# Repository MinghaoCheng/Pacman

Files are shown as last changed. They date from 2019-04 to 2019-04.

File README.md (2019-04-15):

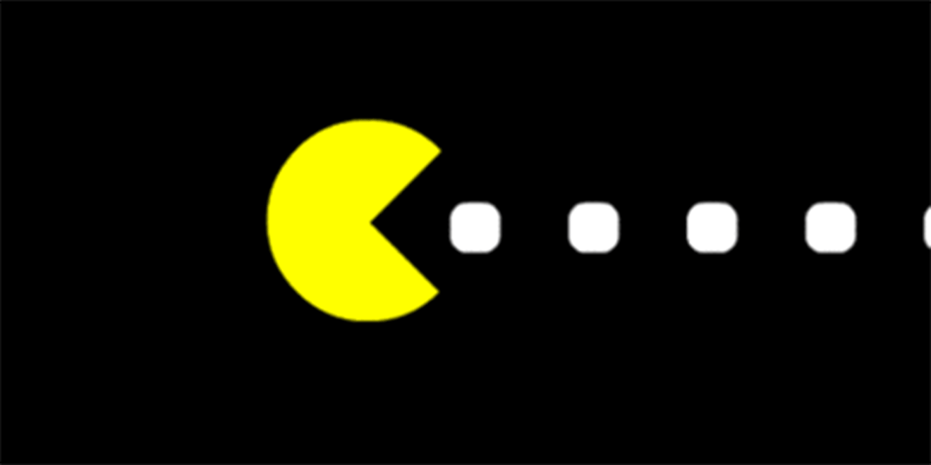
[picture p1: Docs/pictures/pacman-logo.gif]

# Pacman
ENG5220, Embedded real-time programming project, Team19

|Author|Team 19|
|---|---
|E-mail|2359434c@student.gla.ac.uk

* The follwing link is two demostrations of playing the game, catched by the ghost and won the game
https://www.youtube.com/playlist?list=PLmhQhGby8E4eoPKThM3S1RnaBH7sxEcJI

## Motivation& Introduction

As a classic computer game, Pacman impressed lots of people. Now we can do a Pacman game in real life!

This project uses a game panel which contains two 4x4 LED matrices. One of them is in green working as Pacdots, and the other one is in red to represent the Ghost. There is also a 4x4 LDR matrix to give feedback to the host. Three matrices are on the same place and controlled by the host raspberryPi.

There is a car controlled by a raspberryPi which acts as Pacman. It can move around upon the pannel, eat Pacdots and hide from the Ghost.

## Table of contents
* [Getting started](#getting_started)
* [System overview](#system_overview)
* [Required components(BOM)](#required_components(BOM))
* [Assemble](#assemble)
* [Software](#software)
* [Found a bug](#found_a_bug)
* [License](#license)
## Getting started 
1. Buiding hardware  
      Hardware contains PCBs, mechanics, sodering, see [Hardware](#hardware) for details.  
2. Built& install software  
    1. Host  
      To build the software of host: on host raspberryPi, type ```./build_host.sh``` in terminal.  
      To install the software of host:type ```sudo ./install_host.sh``` in terminal. (Only the kernel module needs to be installed)  
    2. Car  
      To build the software of car: on car raspberryPi, type ```./build_car.sh``` in terminal.
3. Execute the programme  
    1. Host  
      Type "sudo ./host_exe" in terminal. (Because this programme would access the kernel module, so it requires super_user)  
    2. Car  
      Type "./car_exe" in terminal.
4. Game rules  
      Once the game starts(After the background music), the Pacdots(green LEDs) would all be on. The Pacman(the Car) would follow the instructions of keyboard connected to the host. If the Pacman eats a Pacdot (car hits the green LED), the LDR would give feedback to the host and shut down the corresponding LED. Meanwhile, a sound would give the player a feedback. The player would win the game when all Pacdots are eaten (a winning music would be played). There is only one ghost(red LED), which would move randomly, if the Pacman hits the ghost, the player will lose (a losing music would be played).  
5. Have fun!  

## System overview
* This project contains a host and a car. The host does the following work:  
    ** Control a red LED matrix using a GPIO extender "MCP23S17" to display the location of the ghost
    ** Control a green LED matrix using a GPIO extender "MCP23S17" to display the pacdots
    ** Control a LDR matrix as the feedback of location of the car
    ** Handle a TCP/IP connection as the server, and send instructions to the car via the connection
    ** Connect with a simple keyboard as input
    ** Output sound through 3.5mm audio jack (Using function "system()" now, I would add ALSA sound driver later)  
* The car work as follow:
    ** Handle a TCP/IP connection as client to receive instructions from the host
    ** Control two motors(which drive the wheels of the car) through a dual H-bridge IC "L298N"
    ** The car sink current from 4xAA batteries and a 5V3A LDO is used.

## Required components(BOM)
* host_0 board

|Component|Quantity|Farnell code|
|---|---|---
|4816P-T02-222LF|1|2908136
|LM2901D|4|1648673
|Resistor,2kΩ,R0805|1|1469887
|Resistor,10kΩ,R0805|2|1469856
|MCP23S17T-E/SS|1|2775058
|pin header 2x8, bended, 2.54mm|2|2984492
|Capacitor, 0.1uF, C0603|1|2280842
|M20-6102045,Connector|1|1569230

* host_1 board

|Component|Quantity|Farnell code|
|---|---|---
|MCP23S17T-E/SS|1|2775058
|BCW66GLT1G|4|2317524
|BCW68GLT1G|4|2317538
|4816P-1-102LF|2|1612549
|M20-6102045,Connector|1|1569230
|pin header 2x8, bended, 2.54mm|1|2984492
|Capacitor, 0.1uF, C0603|1|2280842
|Resistor,200Ω,R0805*|8|1894175

    *:optional,depends on the impedence of the LEDs  

* car_0 board

|Component|Quantity|Farnell code|
|---|---|---
|L298N|1|403295
|NCP59301DS50R4G|1|2774711
|BYG10M-E3/TR|8|9549170
|Capacitor, 0.1uF, C0805|2|

* Others

|Component|Quantity|Farnell code|
|---|---|---
|RapsberryPi model 3B|2|
|Green LED*|16|
|Red LED*|16|
|LDR|16|3168335
|Wires|N/A|
|Panel**|1|

    *:could use any LEDs under 100mA, but the resistors on host_1 board needs to be adjusted  
    **:In this project, the panel was made of a cardboard.
## Assemble
* For PCBs of the host, connect them in the way as follow:  

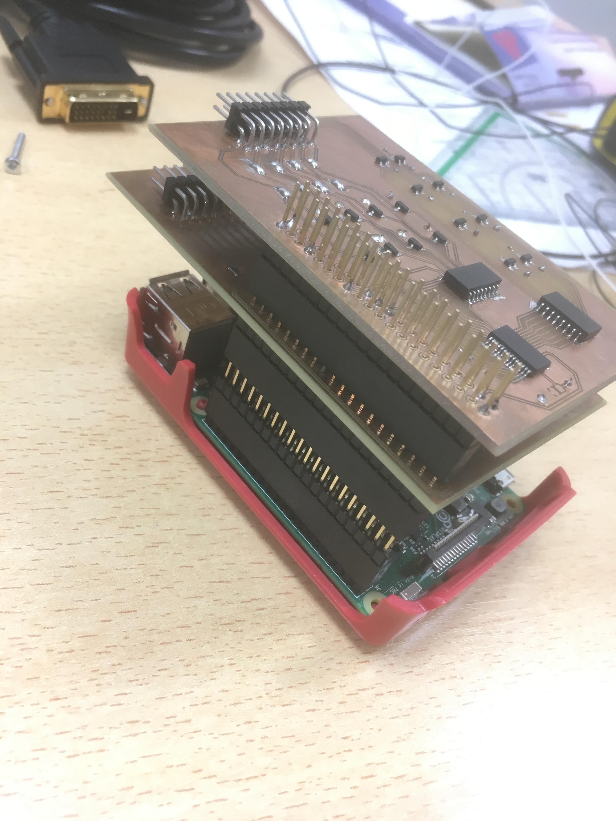
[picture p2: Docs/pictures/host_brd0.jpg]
  

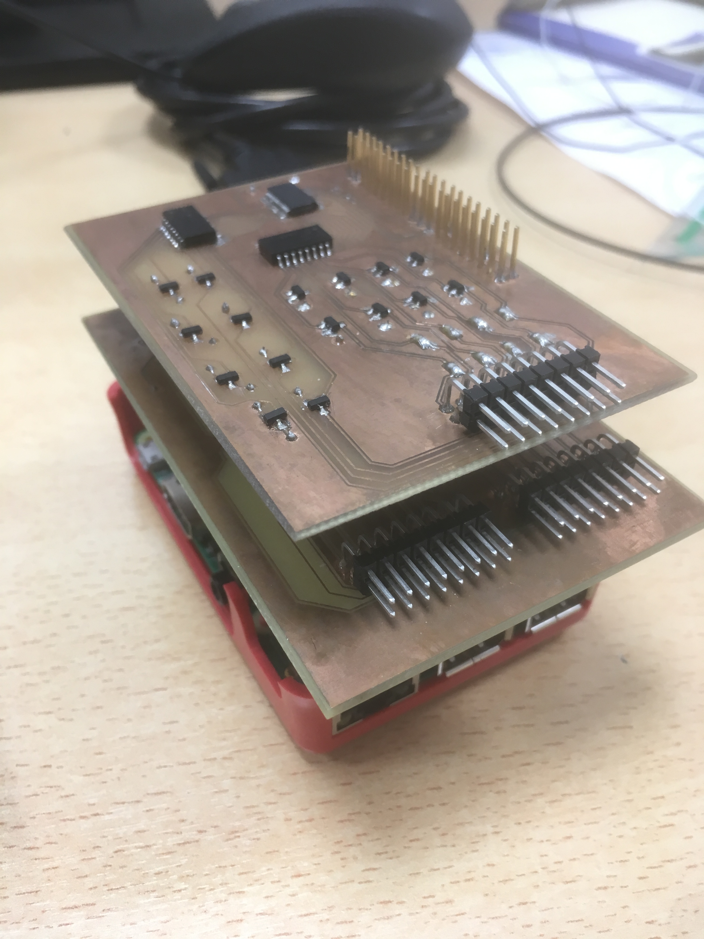
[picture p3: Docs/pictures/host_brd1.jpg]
  

* For LED&LDR matrices, put one green LED, one red LED and one LDR at a single hole on the panel(There are 4x4 holes). Note to put LDR above the LEDs.  

  

* Solder green LED matrix/red LED matrix as follow, this schematic also can be found at [PCBs](/Docs/PCBs):

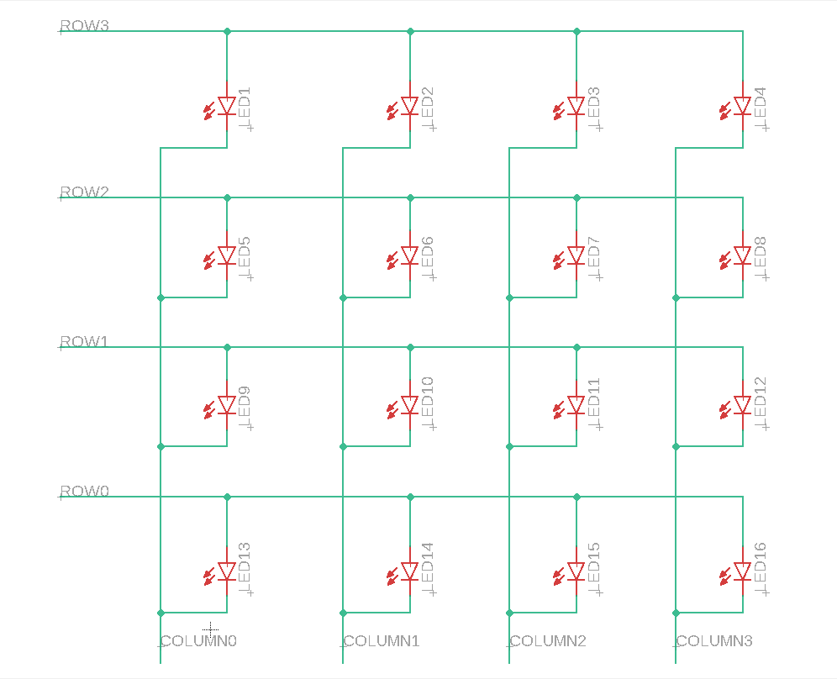
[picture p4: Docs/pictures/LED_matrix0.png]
 

* Solder keyboard following the schematic

* Picture of the system set





## Software
* There are two source codes in this project. One works on the host and another one works on the car.  
* The software of the host contains a kernel module which would work as the driver of the GPIO(it handles GPIO interrupt and output of the GPIO used by the host), and it contains the main codes which works in the user space. There are several components of this software, see details at [Docs](/Docs/software/host)  
* The software of the car controls the motor using L298N through GPIO, and it also receives instructions from the host over TCP/IP through Wi-Fi connection. See details at [Docs](/Docs/software/car)   
* dependency:  
      * host:
      ```pthread, rt, ```
      * car:
      ```pthread```
## Found a bug<a name="found_a_bug">
* Hardware:  
      To isolate the fault of the hardware, the best way is to check the PCB-layouts and schematics.  
      Here is the definition of pins used by the host:  
      
|Raspi-pin|Function|
|---|---
|03|Reset of MCP23S17(s)
|05|INT B of MCP23S17 of LDR board
|07|INT A of MCP23S17 of LDR board
|19|MOSI of SPI bus
|21|MISO of SPI bus
|23|CLK of SPI bus
|24|CS_0 of SPI bus, LDR board
|26|CS_1 of SPI bus, LED board
|29|Keyboard, Left
|31|Keyboard, Up
|33|Keyboard, Right
|35|Keyboard, Down
|37|Keyboard, Reset
      
* Software:
      Remember to add "sudo" to install the host kernel module and execute the programme
      
* For other questions, you can send me an Email with description

## License
See license.md

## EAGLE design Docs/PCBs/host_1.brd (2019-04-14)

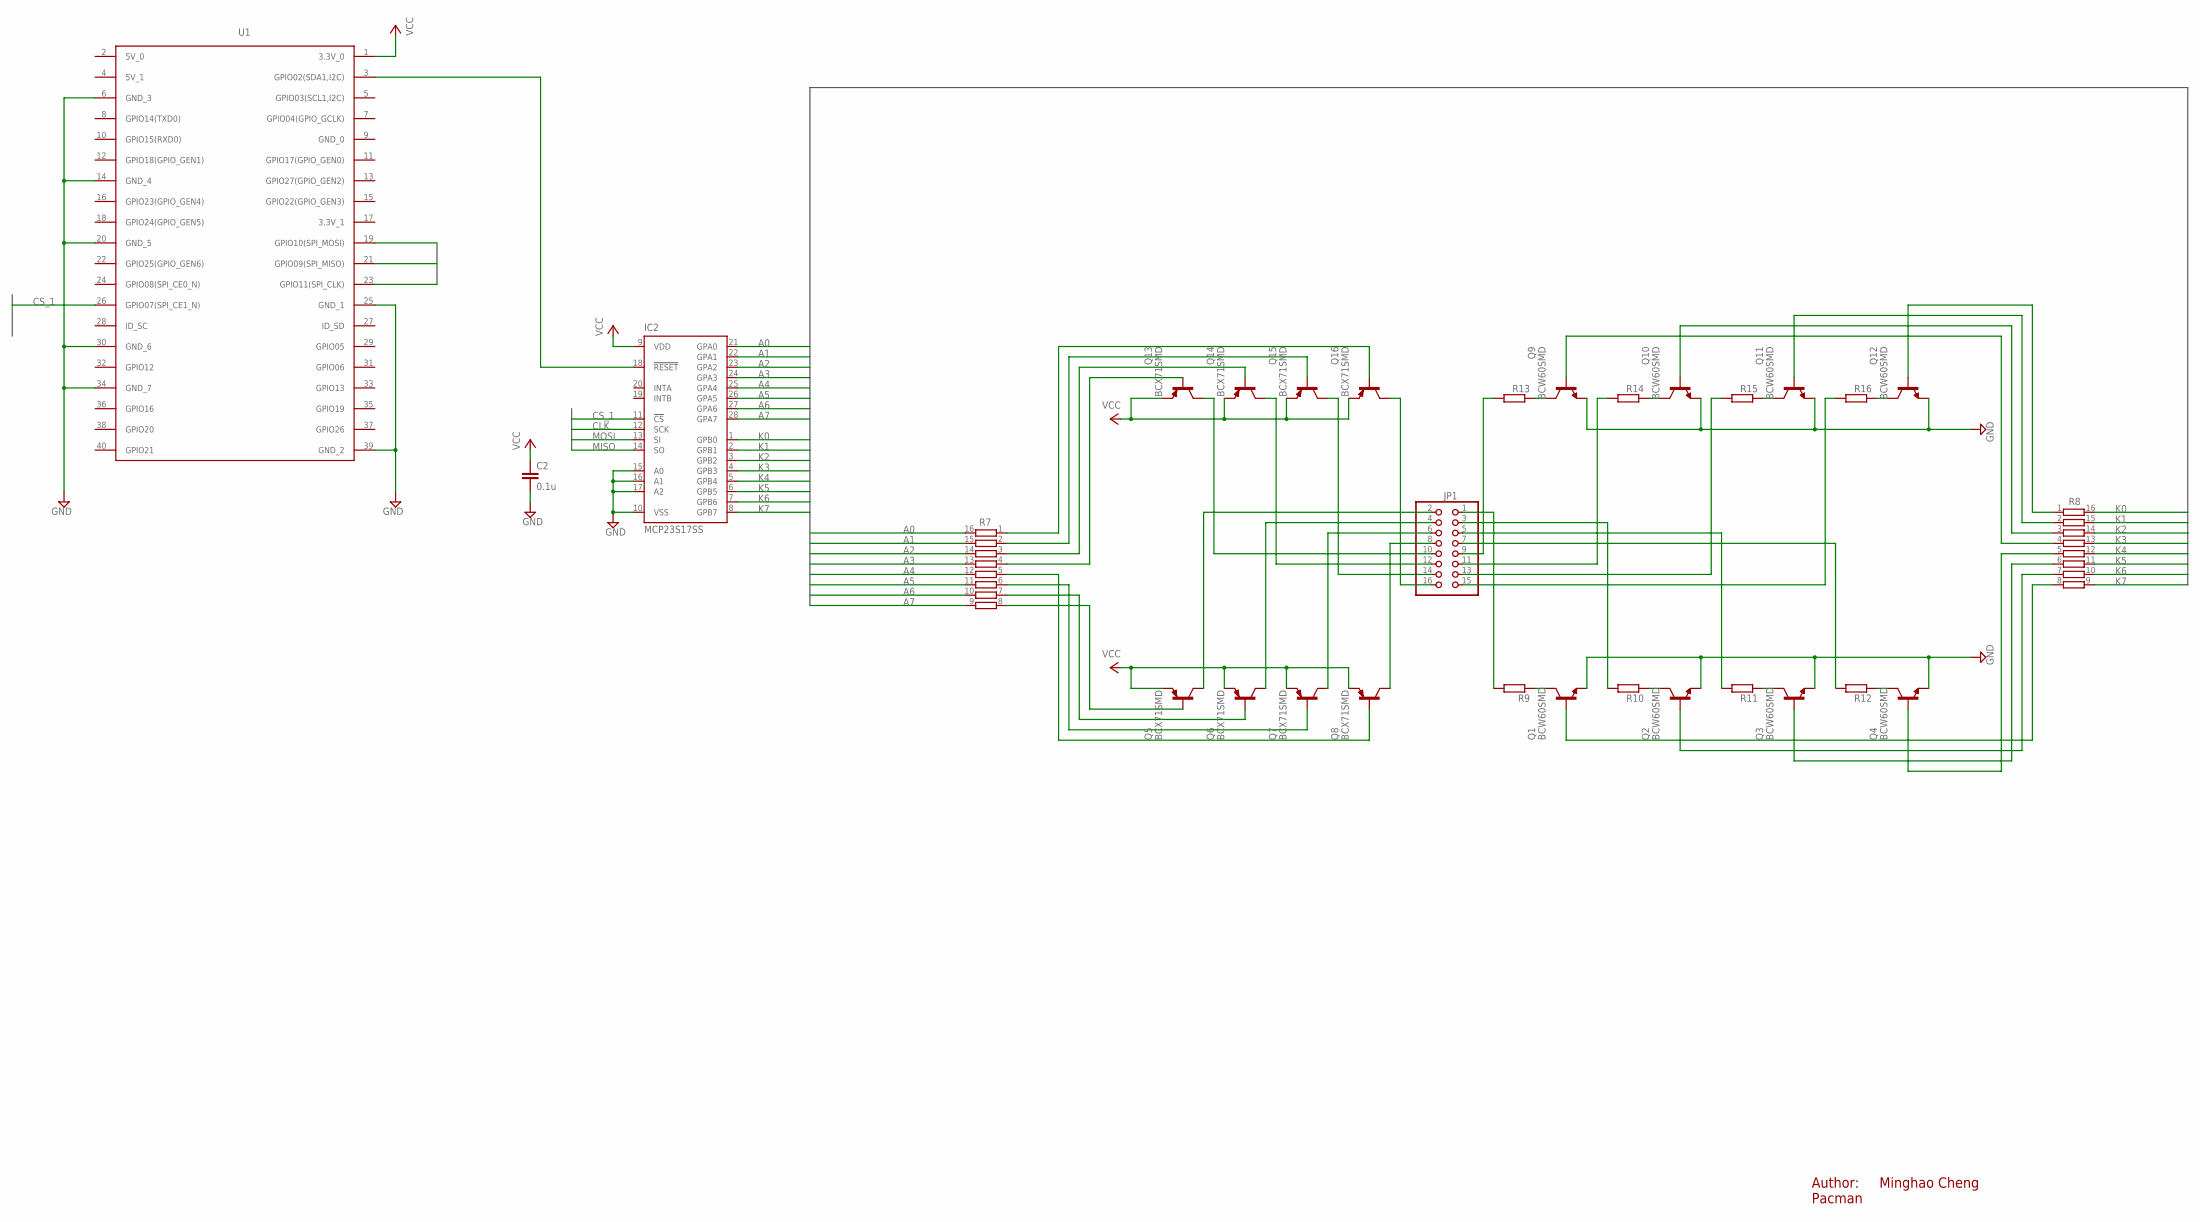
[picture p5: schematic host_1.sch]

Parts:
C2: 0.1u; C0805
IC2: MCP23S17SS; SSOP28
JP1: PINHD-2X8; 2X08
Q1, Q2, Q3, Q4, Q9, Q10, Q11, Q12: BCW60SMD; SOT23-BEC
Q5, Q6, Q7, Q8, Q13, Q14, Q15, Q16: BCX71SMD; SOT23
R7, R8: 4816P-T01; 4816P
R9, R10, R11, R12, R13, R14, R15, R16: 4.7K; R0805
U1: RASPI3_GPIO; FE20-2

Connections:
A0: IC2.21 (GPA0), R7.16
A1: IC2.22 (GPA1), R7.15
A2: IC2.23 (GPA2), R7.14
A3: IC2.24 (GPA3), R7.13
A4: IC2.25 (GPA4), R7.12
A5: IC2.26 (GPA5), R7.11
A6: IC2.27 (GPA6), R7.10
A7: IC2.28 (GPA7), R7.9
CLK: IC2.12 (SCK), U1.23 (GPIO11(SPI_CLK))
CS_1: IC2.11 (!CS), U1.26 (GPIO07(SPI_CE1_N))
GND: C2.2, IC2.10 (VSS), IC2.15 (A0), IC2.16 (A1), IC2.17 (A2), Q1.E, Q2.E, Q3.E, Q4.E, Q9.E, Q10.E, Q11.E, Q12.E, U1.6 (GND_3), U1.14 (GND_4), U1.20 (GND_5), U1.25 (GND_1), U1.30 (GND_6), U1.34 (GND_7), U1.39 (GND_2)
K0: IC2.1 (GPB0), R8.16
K1: IC2.2 (GPB1), R8.15
K2: IC2.3 (GPB2), R8.14
K3: IC2.4 (GPB3), R8.13
K4: IC2.5 (GPB4), R8.12
K5: IC2.6 (GPB5), R8.11
K6: IC2.7 (GPB6), R8.10
K7: IC2.8 (GPB7), R8.9
MISO: IC2.14 (SO), U1.21 (GPIO09(SPI_MISO))
MOSI: IC2.13 (SI), U1.19 (GPIO10(SPI_MOSI))
unnamed: IC2.18 (!RESET), U1.3 (GPIO02(SDA1,I2C))
unnamed: JP1.1, R9.2
unnamed: JP1.3, R10.2
unnamed: JP1.5, R11.2
unnamed: Q5.1 (B), R7.8
unnamed: JP1.7, R12.2
unnamed: JP1.9, R13.2
unnamed: JP1.11, R14.2
unnamed: JP1.13, R15.2
unnamed: JP1.15, R16.2
unnamed: JP1.2, Q5.3 (C)
unnamed: JP1.4, Q6.3 (C)
unnamed: JP1.6, Q7.3 (C)
unnamed: JP1.8, Q8.3 (C)
unnamed: JP1.10, Q13.3 (C)
unnamed: Q1.B, R8.8
unnamed: Q2.B, R8.7
unnamed: Q3.B, R8.6
unnamed: Q4.B, R8.5
unnamed: Q9.B, R8.4
unnamed: Q10.B, R8.3
unnamed: Q11.B, R8.2
unnamed: Q6.1 (B), R7.7
unnamed: Q7.1 (B), R7.6
unnamed: Q8.1 (B), R7.5
unnamed: JP1.12, Q14.3 (C)
unnamed: JP1.14, Q15.3 (C)
unnamed: JP1.16, Q16.3 (C)
unnamed: Q12.B, R8.1
unnamed: Q1.C, R9.1
unnamed: Q2.C, R10.1
unnamed: Q3.C, R11.1
unnamed: Q4.C, R12.1
unnamed: Q13.1 (B), R7.4
unnamed: Q14.1 (B), R7.3
unnamed: Q15.1 (B), R7.2
unnamed: Q16.1 (B), R7.1
unnamed: Q9.C, R13.1
unnamed: Q10.C, R14.1
unnamed: Q11.C, R15.1
unnamed: Q12.C, R16.1
VCC: C2.1, IC2.9 (VDD), Q5.2 (E), Q6.2 (E), Q7.2 (E), Q8.2 (E), Q13.2 (E), Q14.2 (E), Q15.2 (E), Q16.2 (E), U1.1 (3.3V_0)

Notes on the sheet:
Author: Minghao Cheng Pacman

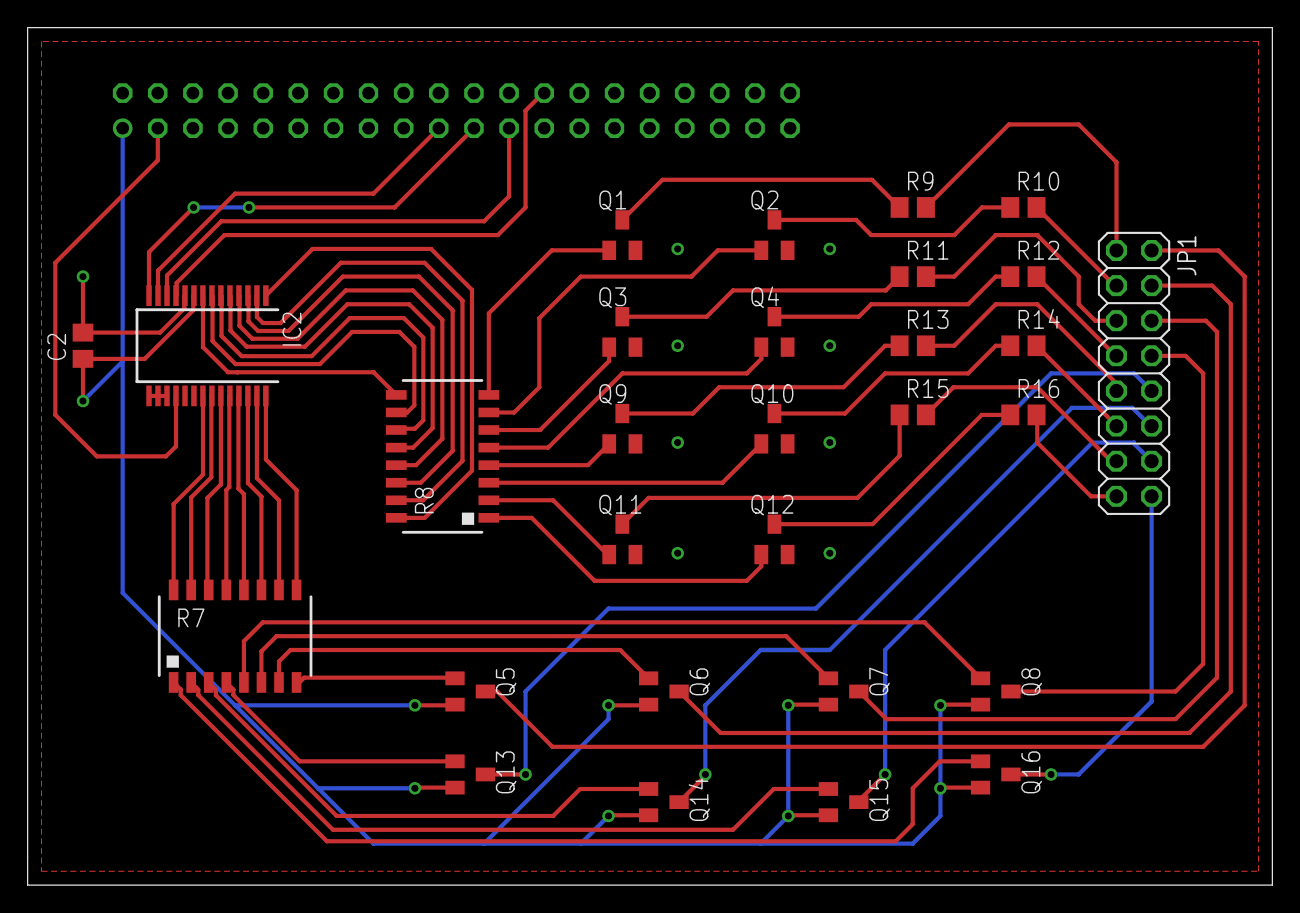
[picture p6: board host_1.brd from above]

Board: 2 copper layers, 90.0 x 62.0 mm, 30 parts (1 on the bottom side), 63 nets.

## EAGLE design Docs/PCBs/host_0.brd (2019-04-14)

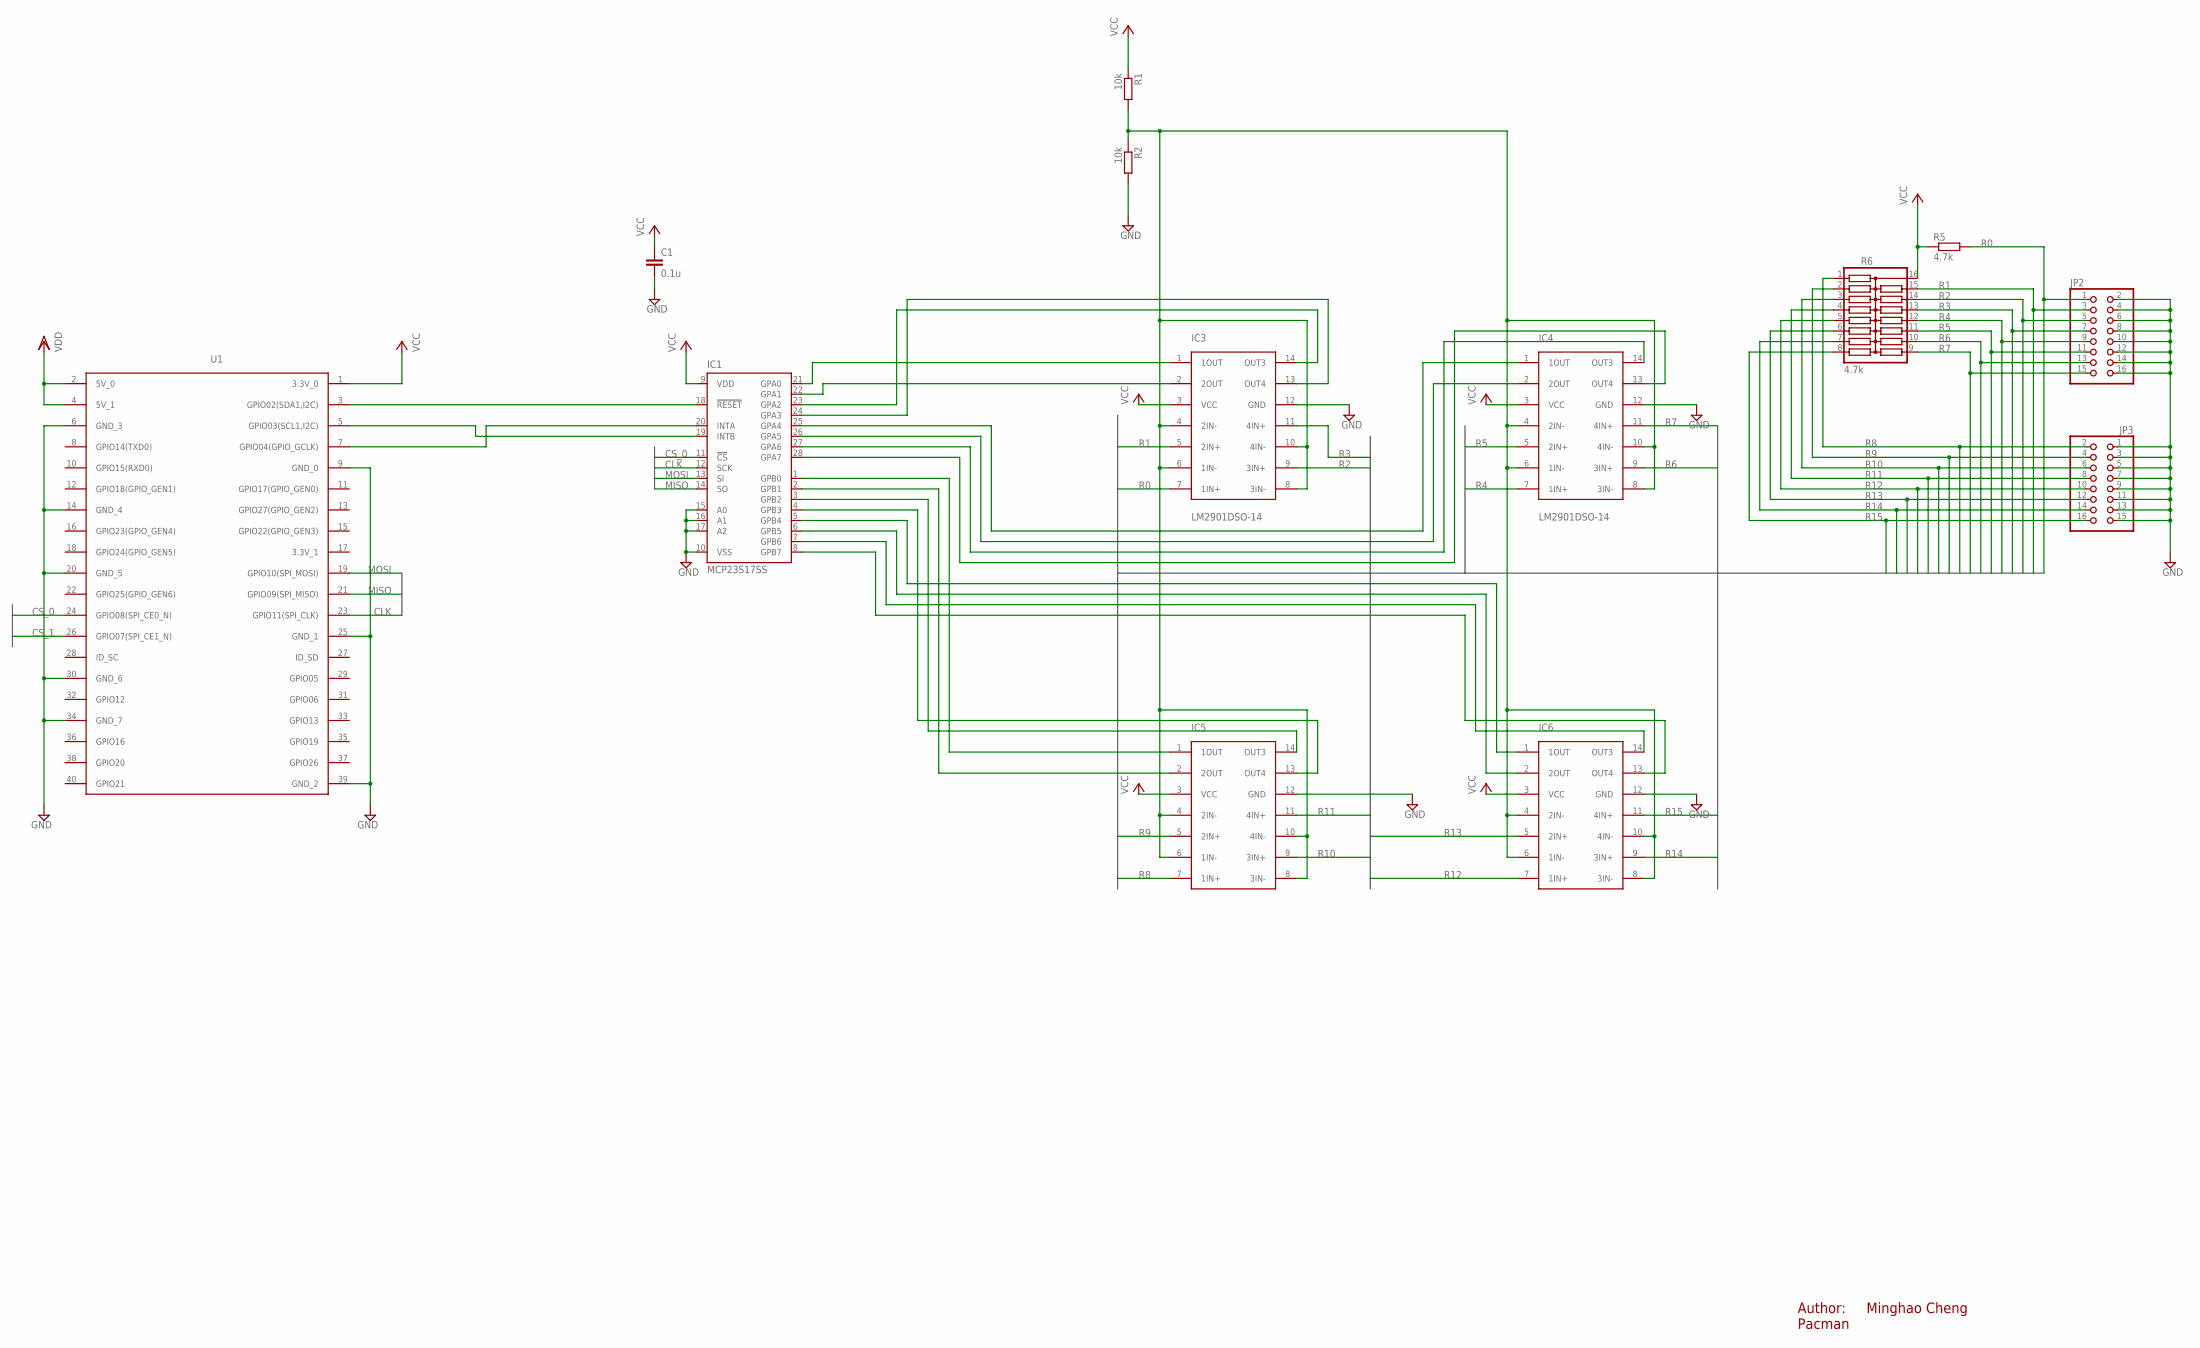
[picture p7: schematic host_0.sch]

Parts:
C1: 0.1u; C0805
IC1: MCP23S17SS; SSOP28
IC3, IC4, IC5, IC6: LM2901DSO-14; SO14
JP2, JP3: PINHD-2X8; 2X08
R1, R2: 10k; R0805
R5: 4.7k; R0805
R6: 4.7k; 4816P
U1: RASPI3_GPIO; FE20-2

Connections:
CLK: IC1.12 (SCK), U1.23 (GPIO11(SPI_CLK))
CS_0: IC1.11 (!CS), U1.24 (GPIO08(SPI_CE0_N))
CS_1: U1.26 (GPIO07(SPI_CE1_N))
GND: C1.2, IC1.10 (VSS), IC1.15 (A0), IC1.16 (A1), IC1.17 (A2), IC3.12 (GND), IC4.12 (GND), IC5.12 (GND), IC6.12 (GND), JP2.2, JP2.4, JP2.6, JP2.8, JP2.10, JP2.12, JP2.14, JP2.16, JP3.1, JP3.3, JP3.5, JP3.7, JP3.9, JP3.11, JP3.13, JP3.15, R2.2, U1.6 (GND_3), U1.9 (GND_0), U1.14 (GND_4), U1.20 (GND_5), U1.25 (GND_1), U1.30 (GND_6), U1.34 (GND_7), U1.39 (GND_2)
MISO: IC1.14 (SO), U1.21 (GPIO09(SPI_MISO))
MOSI: IC1.13 (SI), U1.19 (GPIO10(SPI_MOSI))
unnamed: IC1.18 (!RESET), U1.3 (GPIO02(SDA1,I2C))
unnamed: IC1.20 (INTA), U1.7 (GPIO04(GPIO_GCLK))
unnamed: IC1.19 (INTB), U1.5 (GPIO03(SCL1,I2C))
unnamed: IC1.23 (GPA2), IC3.14 (OUT3)
unnamed: IC1.24 (GPA3), IC3.13 (OUT4)
unnamed: IC3.4 (2IN-), IC3.6 (1IN-), IC3.8 (3IN-), IC3.10 (4IN-), IC4.4 (2IN-), IC4.6 (1IN-), IC4.8 (3IN-), IC4.10 (4IN-), IC5.4 (2IN-), IC5.6 (1IN-), IC5.8 (3IN-), IC5.10 (4IN-), IC6.4 (2IN-), IC6.6 (1IN-), IC6.8 (3IN-), IC6.10 (4IN-), R1.2, R2.1
unnamed: IC1.21 (GPA0), IC3.1 (1OUT)
unnamed: IC1.22 (GPA1), IC3.2 (2OUT)
unnamed: IC1.25 (GPA4), IC4.1 (1OUT)
unnamed: IC1.26 (GPA5), IC4.2 (2OUT)
unnamed: IC1.27 (GPA6), IC4.14 (OUT3)
unnamed: IC1.28 (GPA7), IC4.13 (OUT4)
unnamed: IC1.1 (GPB0), IC5.1 (1OUT)
unnamed: IC1.2 (GPB1), IC5.2 (2OUT)
unnamed: IC1.3 (GPB2), IC5.14 (OUT3)
unnamed: IC1.5 (GPB4), IC6.1 (1OUT)
unnamed: IC1.4 (GPB3), IC5.13 (OUT4)
unnamed: IC1.6 (GPB5), IC6.2 (2OUT)
unnamed: IC1.7 (GPB6), IC6.14 (OUT3)
unnamed: IC1.8 (GPB7), IC6.13 (OUT4)
R0: IC3.7 (1IN+), JP2.1, R5.2
R1: IC3.5 (2IN+), JP2.3, R6.15
R2: IC3.9 (3IN+), JP2.5, R6.14
R3: IC3.11 (4IN+), JP2.7, R6.13
R4: IC4.7 (1IN+), JP2.9, R6.12
R5: IC4.5 (2IN+), JP2.11, R6.11
R6: IC4.9 (3IN+), JP2.13, R6.10
R7: IC4.11 (4IN+), JP2.15, R6.9
R8: IC5.7 (1IN+), JP3.2, R6.1
R9: IC5.5 (2IN+), JP3.4, R6.2
R10: IC5.9 (3IN+), JP3.6, R6.3
R11: IC5.11 (4IN+), JP3.8, R6.4
R12: IC6.7 (1IN+), JP3.10, R6.5
R13: IC6.5 (2IN+), JP3.12, R6.6
R14: IC6.9 (3IN+), JP3.14, R6.7
R15: IC6.11 (4IN+), JP3.16, R6.8
VCC: C1.1, IC1.9 (VDD), IC3.3 (VCC), IC4.3 (VCC), IC5.3 (VCC), IC6.3 (VCC), R1.1, R5.1, R6.16, U1.1 (3.3V_0)
VDD: U1.2 (5V_0), U1.4 (5V_1)

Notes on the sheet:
Author: Minghao Cheng Pacman

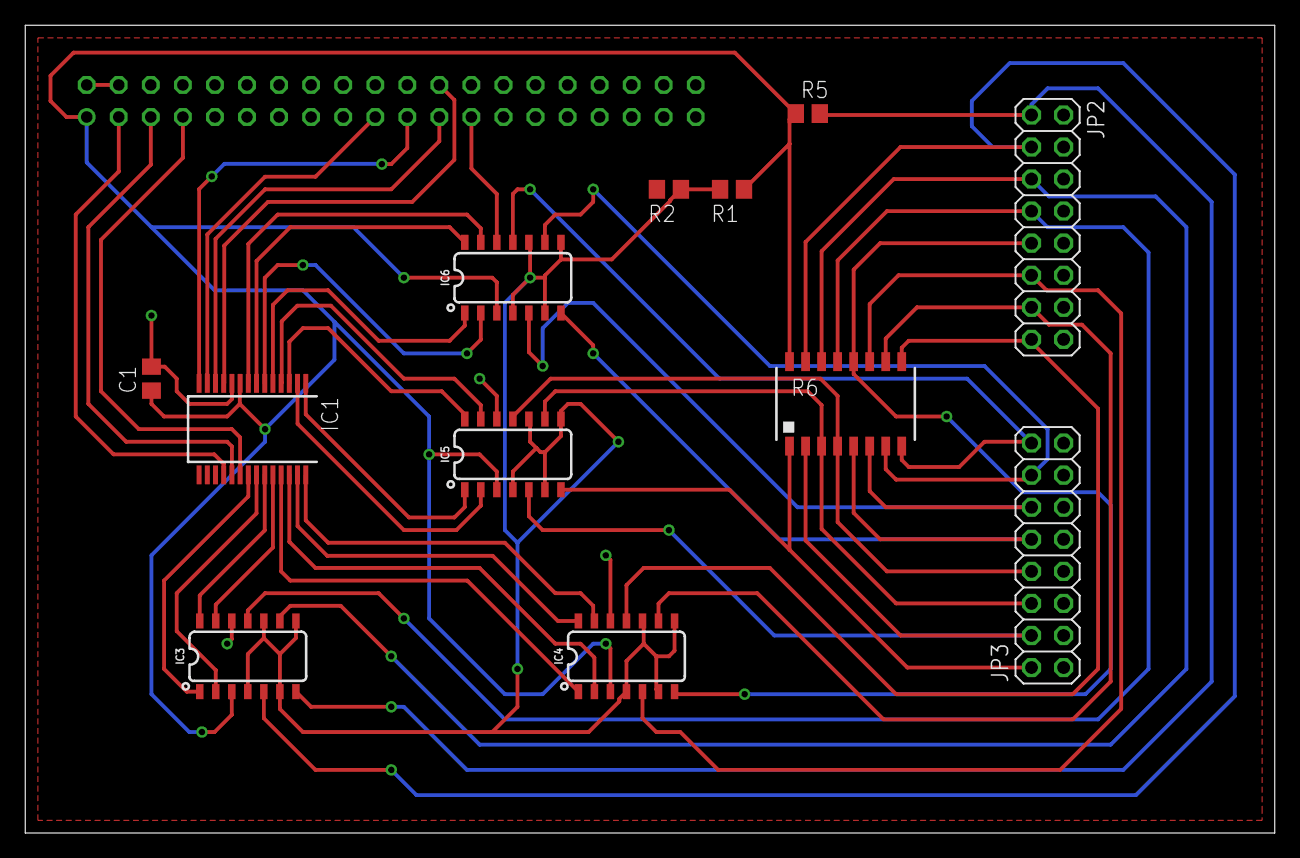
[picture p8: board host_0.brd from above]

Board: 2 copper layers, 99.0 x 64.0 mm, 13 parts (1 on the bottom side), 43 nets.

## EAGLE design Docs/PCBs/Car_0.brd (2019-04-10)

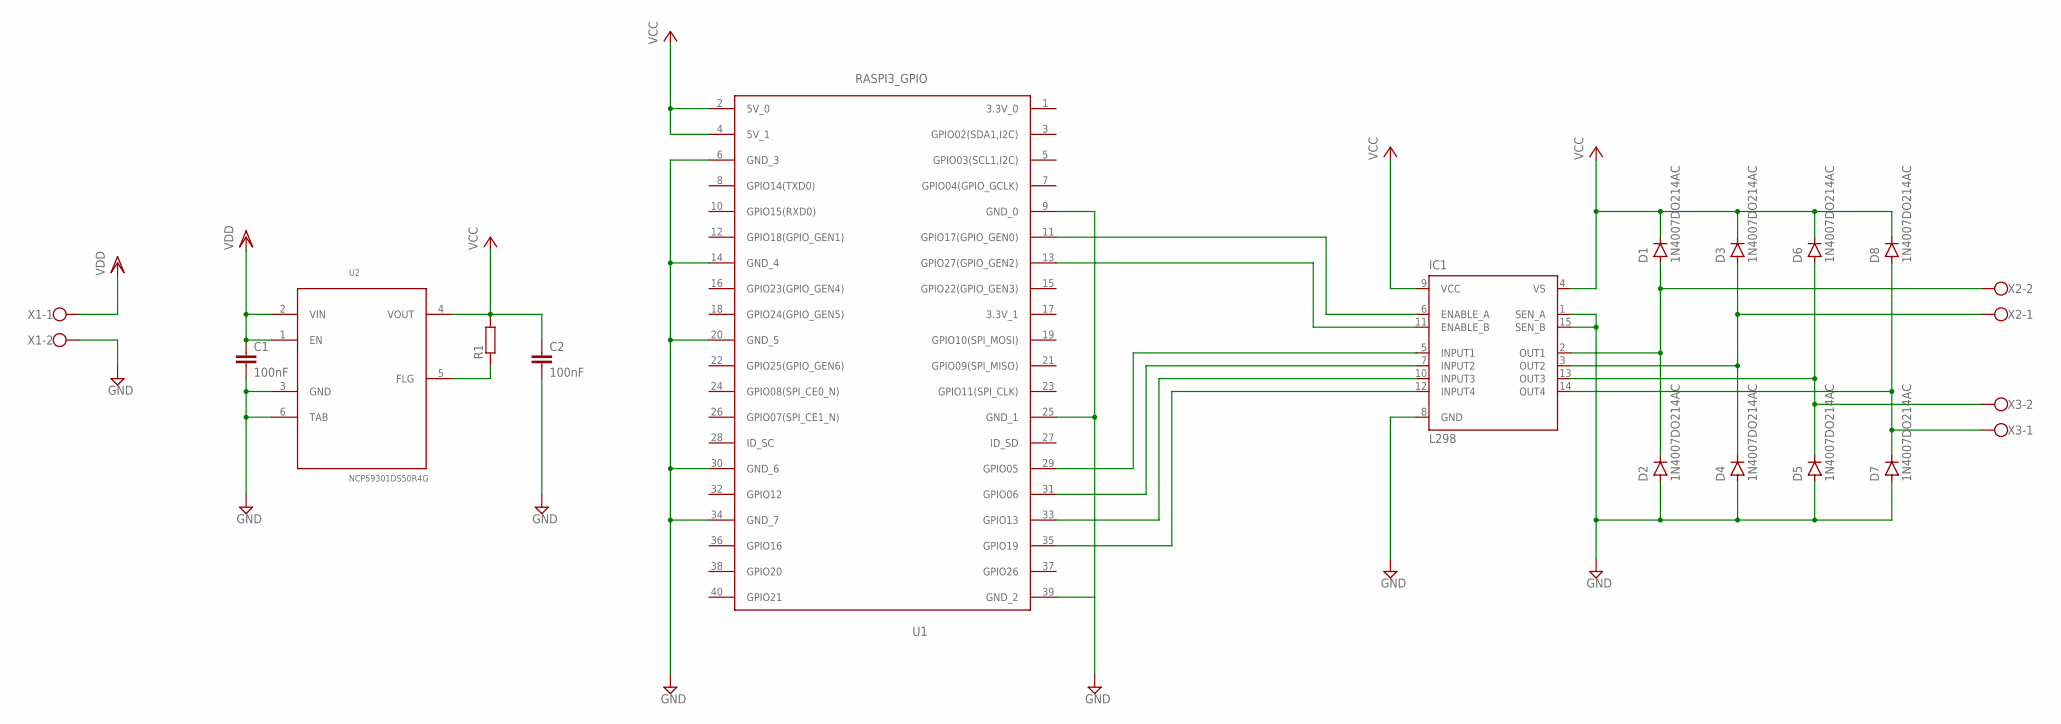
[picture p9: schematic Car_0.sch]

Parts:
C1, C2: 100nF; C0805
D1, D2, D3, D4, D5, D6, D7, D8: 1N4007DO214AC; SMA-DO214AC
IC1: L298; MULTIWATT-15
R1: R-EU_R0805; R0805
U1: RASPI3_GPIO; FE20-2
U2: NCP59301DS50R4G; TO263-5
X1, X2, X3: W237-102

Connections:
GND: C1.2, C2.2, D2.A, D4.A, D5.A, D7.A, IC1.1 (SEN_A), IC1.8 (GND), IC1.15 (SEN_B), U1.6 (GND_3), U1.9 (GND_0), U1.14 (GND_4), U1.20 (GND_5), U1.25 (GND_1), U1.30 (GND_6), U1.34 (GND_7), U1.39 (GND_2), U2.3 (GND), U2.6 (TAB), X1.2
unnamed: D1.A, D2.K (C), IC1.2 (OUT1), X2.2
unnamed: D3.A, D4.K (C), IC1.3 (OUT2), X2.1
unnamed: D5.K (C), D6.A, IC1.13 (OUT3), X3.2
unnamed: D7.K (C), D8.A, IC1.14 (OUT4), X3.1
unnamed: IC1.6 (ENABLE_A), U1.11 (GPIO17(GPIO_GEN0))
unnamed: IC1.11 (ENABLE_B), U1.13 (GPIO27(GPIO_GEN2))
unnamed: IC1.5 (INPUT1), U1.29 (GPIO05)
unnamed: IC1.7 (INPUT2), U1.31 (GPIO06)
unnamed: IC1.10 (INPUT3), U1.33 (GPIO13)
unnamed: IC1.12 (INPUT4), U1.35 (GPIO19)
unnamed: R1.1, U2.5 (FLG)
VCC: C2.1, D1.K (C), D3.K (C), D6.K (C), D8.K (C), IC1.4 (VS), IC1.9 (VCC), R1.2, U1.2 (5V_0), U1.4 (5V_1), U2.4 (VOUT)
VDD: C1.1, U2.1 (EN), U2.2 (VIN), X1.1

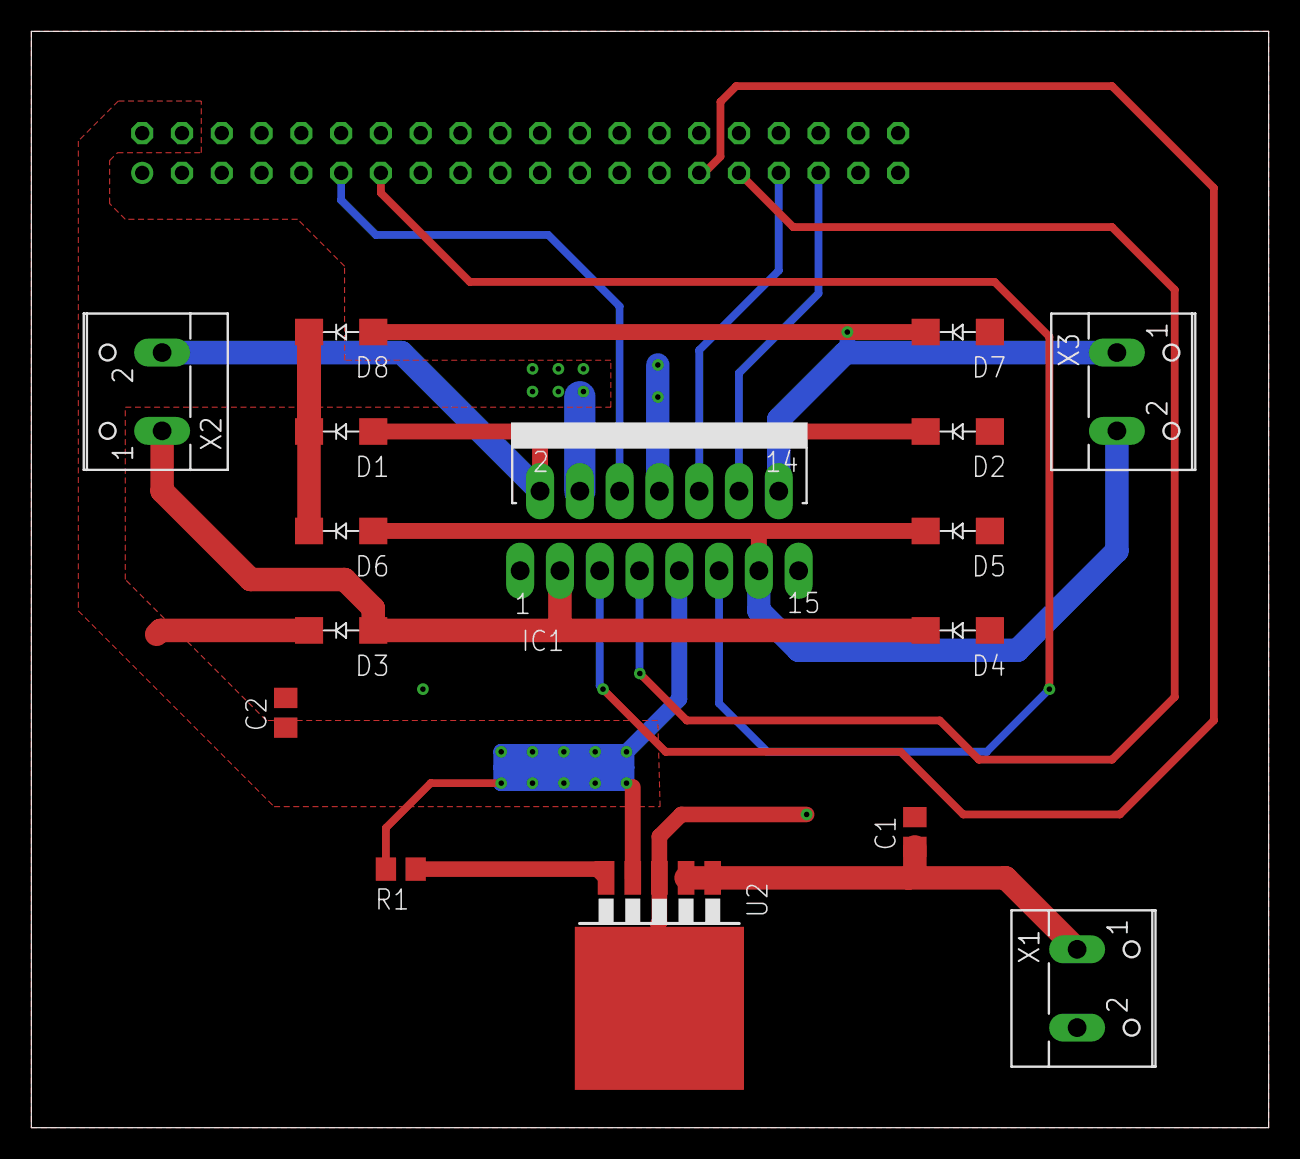
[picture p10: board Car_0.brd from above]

Board: 2 copper layers, 79.0 x 70.0 mm, 17 parts (1 on the bottom side), 14 nets.

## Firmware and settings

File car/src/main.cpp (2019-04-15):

#include <stdio.h>
#include <wiringPi.h>
#include <signal.h>
#include <stdlib.h>
#include <pthread.h>
#include <stdio.h> 
#include <sys/socket.h> 
#include <netinet/in.h> 
#include <arpa/inet.h>
#include <string.h> 
#include <unistd.h>
#include "control.h"
#define PORT 3210 


void exit_handler(int signo)// function use ctrl + c to interrupt program
{
	stop();
	
	exit(0);
}

int dir;
void *keyboard(void *arg)// keyboard function use 1,2,3,4,5,6 to control car 
{
	while(1)
			switch(dir)
			{
				case 2:
					stop();
					break;
				case 1:
					forward();
					break;
				case 5:
					stop();
					break;
				case 3:
					turnleft();
					break;
				case 4:
					turnright();
					break;
				default:
					break;
			}	
}


int main(int argc, char const *argv[])// main function
{	
	wiringPiSetup();//set up gpio
	signal(SIGINT, exit_handler);  // ctrl+c to interrupt
	pinMode(0, OUTPUT);
	pinMode(2, OUTPUT);
	pinMode(21, OUTPUT);
	pinMode(22, OUTPUT);
	pinMode(23, OUTPUT);
	pinMode(24, OUTPUT);
	stop();
	pthread_t id;// call thread
	pthread_create(&id, NULL, keyboard, NULL);


	int i;
	struct sockaddr_in address; // use socket
       int sock = 0, valread; 
       struct sockaddr_in serv_addr; 
    	const char *hello = "Hello from client"; 
    	char buffer[1024] = {0}; 
    	if ((sock = socket(AF_INET, SOCK_STREAM, 0)) < 0) //wrong creation 
    	{ 
        	printf("\n Socket creation error \n"); 
        	return -1; 
    	} 
   
    	memset(&serv_addr, '0', sizeof(serv_addr)); 
   
    	serv_addr.sin_family = AF_INET; 
    	serv_addr.sin_port = htons(PORT); 
       
    	// Convert IPv4 and IPv6 addresses from text to binary form 
    	if(inet_pton(AF_INET, "192.168.0.103", &serv_addr.sin_addr)<=0)  
    	{ 
        	printf("\nInvalid address/ Address not supported \n"); 
        	return -1; 
    	} 
   
    	if (connect(sock, (struct sockaddr *)&serv_addr, sizeof(serv_addr)) 	< 0) 
    	{ 
        	printf("\nConnection Failed \n"); 
        	return -1; 
    	} 
    	send(sock , hello , strlen(hello) , 0 ); 
    	printf("Hello message sent\n"); 
    
	while(1)
		{
			valread = read( sock , buffer, 1024);
			//scanf("%d", &buffer[0]);
			if(valread>0)
			{
				printf("Byte received, val = %x\n",buffer[0]);
				dir = buffer[0];
			}
		}//while
		return 0;
	}//main

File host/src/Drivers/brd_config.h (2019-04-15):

/*
 * GNU GENERAL PUBLIC LICENSE
 * Version 1, Mar 2019
 *
 * (C) 2019, Minghao Cheng <chengminghao92@gmail.com>
 */
#ifndef _BRD_CONFIG_H_
#define _BRD_CONFIG_H_

/**
 * Pacman device param specification
 */
#define LED_MATRIX_ROW                      4
#define LED_MATRIX_COLUMN                   4
#define LED_GPIO_SPI_CHANNEL                1
#define LED_ROW_REFRESH_PERIOD_US           1000 // matrix.fps = 1/row_refresh/row

#define LDR_GPIO_SPI_CHANNEL                0
#define LDR_GPIO_WIDTH                      8

#define TCP_SOCKET                          3210

#endif

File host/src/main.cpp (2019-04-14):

/*
 * GNU GENERAL PUBLIC LICENSE
 * Version 1, Mar 2019
 *
 * (C) 2019, Minghao Cheng <chengminghao92@gmail.com>
 */
#include <stdio.h>
#include <stdint.h>

#include "Game.h"
int main(void)
{
    Game game_instance(0);
    if(-1 == game_instance.init())
    {
        printf("Initialising failed\n");
        return -1;
    }
    game_instance.thread_start();
    while(1)
    {
        sleep(100);
    }
}

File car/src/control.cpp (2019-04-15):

#include <stdio.h>
#include <wiringPi.h>
#include <signal.h>
#include <stdlib.h>



void changespeed(int pin, int speed)// change speed fucntion  
{					
	int i;
	for(i=0; i<20; i++)
	{  //  use function x/1000 to change speed within 1000
		digitalWrite(pin, HIGH);
		delayMicroseconds(speed);
		digitalWrite(pin, LOW);
		delayMicroseconds(1000-speed);
	}
}

void forward()// forward function
{
	digitalWrite(21, LOW); 
	digitalWrite(22, HIGH); 
	digitalWrite(23, HIGH); 
	digitalWrite(24, LOW); 
	
	changespeed(0, 900);
	changespeed(2, 900);
}


void backward()// backward function
{
	digitalWrite(21, LOW); 
	digitalWrite(22, HIGH); 
	digitalWrite(23, HIGH); 
	digitalWrite(24, LOW); 
	
	changespeed(0, 900);
	changespeed(2, 900);
}



void turnright()// turn right function
{
	digitalWrite(21, LOW); 
	digitalWrite(22, HIGH); 
	
	digitalWrite(23, LOW); 
	digitalWrite(24, HIGH); 
	
	changespeed(0, 900);
	//changespeed(2, 900);
}

void turnleft()// turn left function
{
	digitalWrite(21, HIGH); 
	digitalWrite(22, LOW); 
	
	digitalWrite(23, HIGH); 
	digitalWrite(24, LOW); 
	
	//changespeed(0, 900);
	changespeed(2, 900);
}


void stop()// stop function 
{
	digitalWrite(21, LOW); 
	digitalWrite(22, LOW); 
	digitalWrite(23, LOW); 
	digitalWrite(24, LOW); 
	digitalWrite(0, LOW); 
	digitalWrite(2, LOW); 
}

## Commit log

2019-02-25 user space SPI driver added. MCP23s17 driver added, test version
2019-02-25 SPI/mcp23s17 drivers test version
2019-03-05 thread class update
2019-03-17 led matrix driver added
2019-03-18 timer test update
2019-03-26 game hardware driver update
2019-03-28 LDR INT mapping, timer tested
2019-04-09 Readme changed, updates with LED panel driver
2019-04-10 general timer added
2019-04-10 LED_matrix schematic
    [LED_matrix.sch]
2019-04-13 in TCP, use poll()and recv() to check socket connection instead of read(), because of SIGRTMIN (SIG34) would interrupt the read() function (read() function is using select() inside)
2019-04-14 Comments updated
    [Car_0.sch, LED_matrix.sch, host_0.brd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]
2019-04-14 Keyboard sch added
    [LED_matrix&Keyboard.sch]

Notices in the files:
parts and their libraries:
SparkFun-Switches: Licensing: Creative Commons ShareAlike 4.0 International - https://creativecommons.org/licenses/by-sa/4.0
